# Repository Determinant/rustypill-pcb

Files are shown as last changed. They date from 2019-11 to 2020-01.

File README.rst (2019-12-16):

rustypill
---------

A uniform design for my daily/IoT DIY need.

Features
========

- STM32F103CBU6/STM32F411CEU6 microcontroller (required)
- All GPIOs are available
- Support optional HD44780 LCD (or "1602", with backlight) via I2C
- Support optional ESP8266 (WiFi module), via UART serial ports
- Support optional DS3231 (accurate RTC, with battery) via I2C
- Support optional AT24Cx (EEPROM) via I2C
- Support optional microSD via SPI
- Support optional custom I2C external board (such as OLED display)
- Convenient 10-pin IDC socket (A0-A7 which supports analog input, plus GND and V5 power)
- microUSB

PCB
===

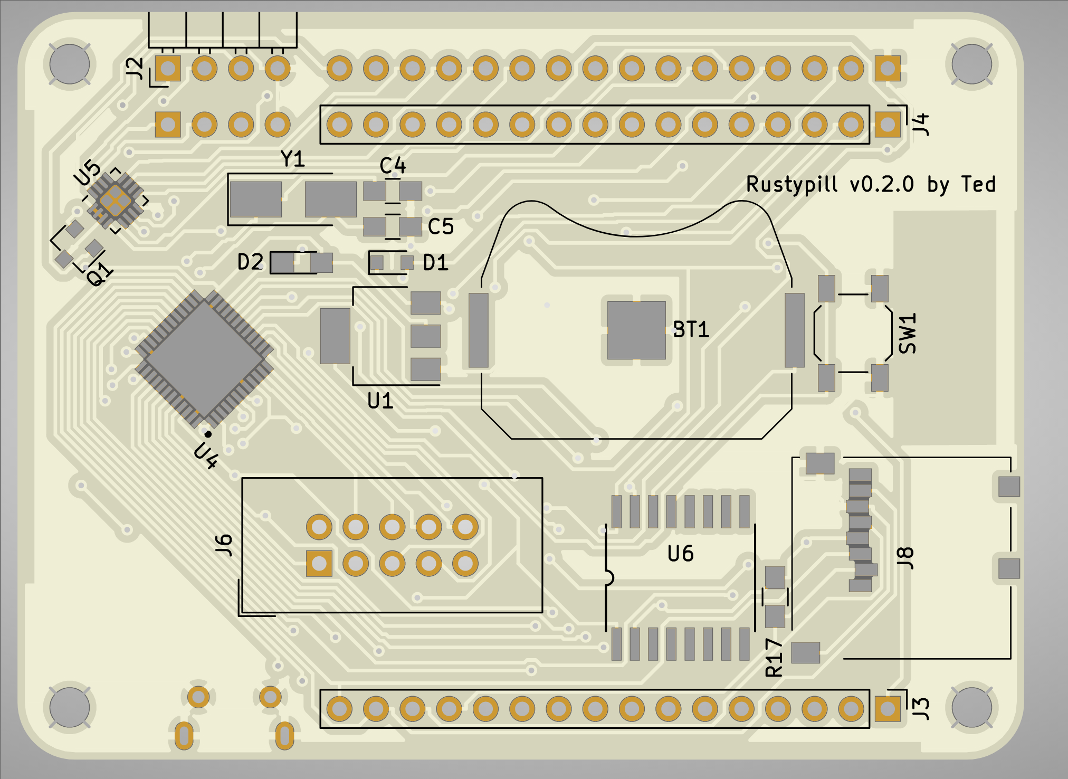
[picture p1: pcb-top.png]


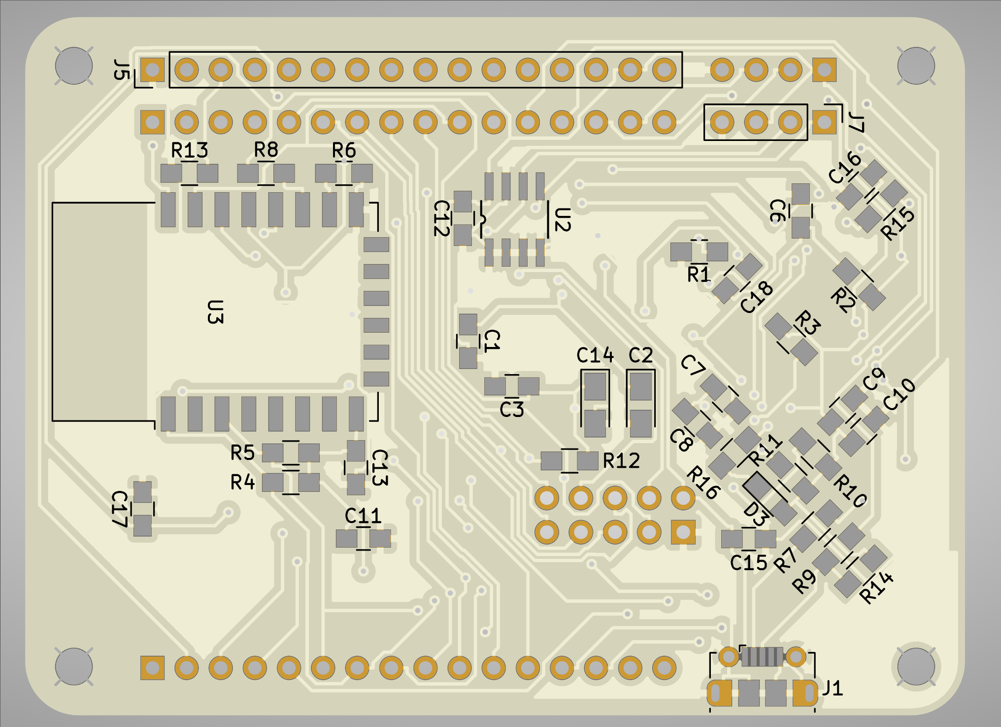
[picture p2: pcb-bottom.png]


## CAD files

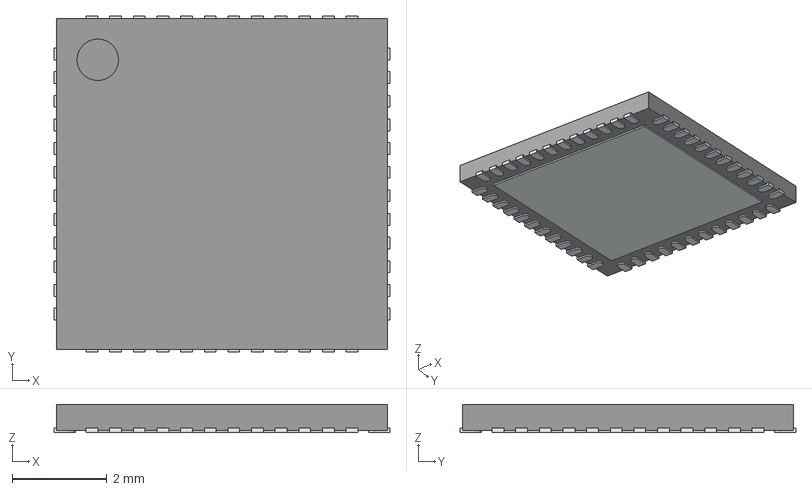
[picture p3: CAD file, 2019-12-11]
3D/STM32F411CEU6.stp
7.10 x 7.10 x 0.6 mm
ThermalPin
PinsArrayLR
PinsArrayTB

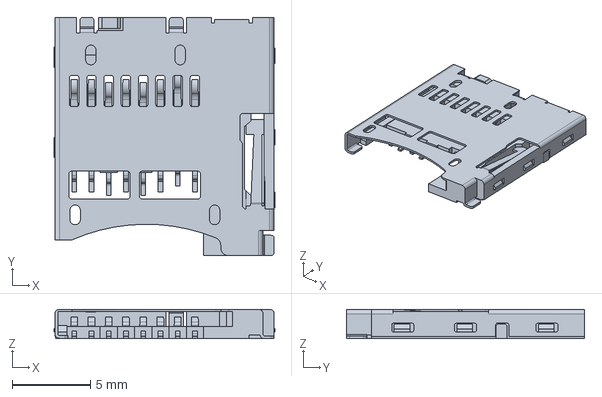
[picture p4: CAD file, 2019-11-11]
3D/47334-0001.stp
14.1 x 15.2 x 1.88 mm

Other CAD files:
3D/STM32F411CEU6.stl

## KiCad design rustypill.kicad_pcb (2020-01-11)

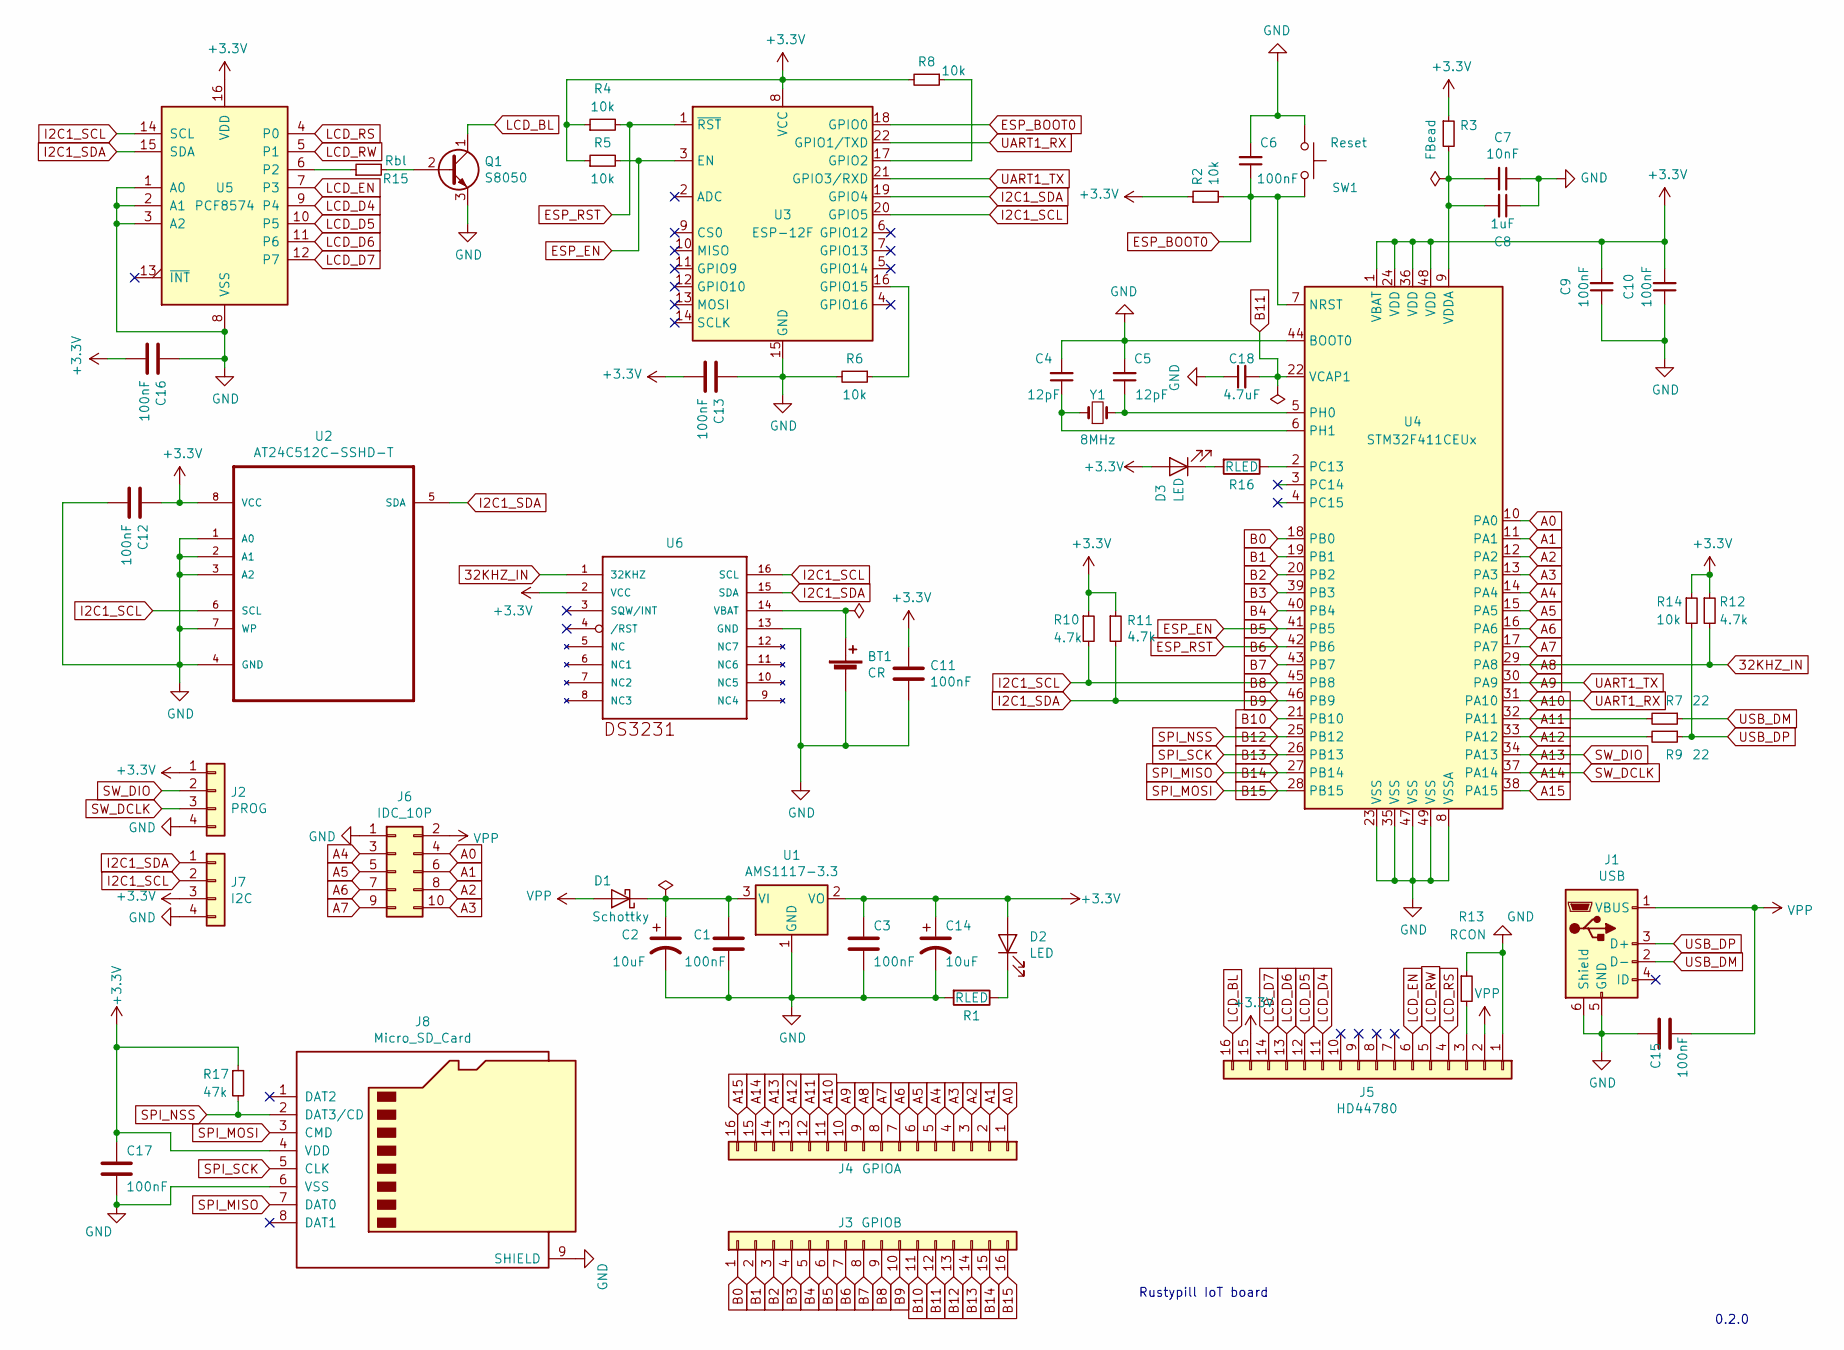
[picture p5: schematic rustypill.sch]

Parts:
BT1: CR; my3034_holder
C1, C3, C6, C9, C10, C11, C12, C13, C15, C16, C17: 100nF; C_0805_HandSoldering
C2, C14: 10uF; CP_Tantalum_Case-A_EIA-3216-18_Reflow
C4, C5: 12pF; C_0805_HandSoldering
C7: 10nF; C_0805_HandSoldering
C8: 1uF; C_0805_HandSoldering
C18: 4.7uF; C_0805_HandSoldering
D1: Schottky; D_0805
D2, D3: LED; LED_0805_HandSoldering
J1: USB; USB_Micro-B_Molex-105017-0001
J2: PROG; Pin_Header_Angled_1x04_Pitch2.54mm
J3: GPIOB; Pin_Header_Straight_1x16_Pitch2.54mm
J4: GPIOA; Pin_Header_Straight_1x16_Pitch2.54mm
J5: HD44780; Pin_Header_Straight_1x16_Pitch2.54mm
J6: IDC_10P; IDC-Header_2x05_P2.54mm_Vertical
J7: I2C; Pin_Header_Straight_1x04_Pitch2.54mm
J8: Micro_SD_Card; 473340001
Q1: S8050; SOT-23
R1, R16: RLED; R_0805_HandSoldering
R2, R4, R5, R6, R8, R14: 10k; R_0805_HandSoldering
R3: FBead; R_0805_HandSoldering
R7, R9: 22; R_0805_HandSoldering
R10, R11, R12: 4.7k; R_0805_HandSoldering
R13: RCON; R_0805_HandSoldering
R15: Rbl; R_0805_HandSoldering
R17: 47k; R_0805_HandSoldering
SW1: Reset; SW_SPST_SKQG
U1: AMS1117-3.3; SOT-223-3_TabPin2
U2: AT24C512C-SSHD-T; at24c512c-sshd-t
U3: ESP-12F; ESP-12E
U4: STM32F411CEUx; stm32f411ceu6
U5: PCF8574; VQFN-16-1EP_3x3mm_P0.5mm_EP1.68x1.68mm
U6: DS3231; ds3231
Y1: 8MHz; Crystal_SMD_5032-2pin_5.0x3.2mm_HandSoldering

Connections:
32KHZ_IN: J4.9, R12.2, U4.29 (PA8), U6.1 (32KHZ)
+3V3: C3.1, C9.2, C10.2, C11.1, C12.1, C13.2, C14.1, C16.2, C17.1, D2.2 (A), D3.2 (A), J2.1, J5.15, J7.3, J8.4 (VDD), R2.1, R3.1, R4.1, R5.1, R8.2, R10.1, R11.1, R12.1, R14.1, R17.1, U1.2 (VO), U2.8 (VCC), U3.8 (VCC), U4.1 (VBAT), U4.24 (VDD), U4.36 (VDD), U4.48 (VDD), U5.16 (VDD), U6.2 (VCC)
A0: J4.1, J6.4, U4.10 (PA0)
A1: J4.2, J6.6, U4.11 (PA1)
A2: J4.3, J6.8, U4.12 (PA2)
A3: J4.4, J6.10, U4.13 (PA3)
A4: J4.5, J6.3, U4.14 (PA4)
A5: J4.6, J6.5, U4.15 (PA5)
A6: J4.7, J6.7, U4.16 (PA6)
A7: J4.8, J6.9, U4.17 (PA7)
A9: J4.10, U3.21 (GPIO3/RXD), U4.30 (PA9)
A10: J4.11, U3.22 (GPIO1/TXD), U4.31 (PA10)
A11: J4.12, R7.2, U4.32 (PA11)
A12: J4.13, R9.2, U4.33 (PA12)
A13: J2.2, J4.14, U4.34 (PA13)
A14: J2.3, J4.15, U4.37 (PA14)
A15: J4.16, U4.38 (PA15)
B0: J3.1, U4.18 (PB0)
B1: J3.2, U4.19 (PB1)
B2: J3.3, U4.20 (PB2)
B3: J3.4, U4.39 (PB3)
B4: J3.5, U4.40 (PB4)
B5: J3.6, R5.2, U3.3 (EN), U4.41 (PB5)
B6: J3.7, R4.2, U3.1 (~RST), U4.42 (PB6)
B7: J3.8, U4.43 (PB7)
B8: J3.9, J7.2, R10.2, U2.6 (SCL), U3.20 (GPIO5), U4.45 (PB8), U5.14 (SCL), U6.16 (SCL)
B9: J3.10, J7.1, R11.2, U2.5 (SDA), U3.19 (GPIO4), U4.46 (PB9), U5.15 (SDA), U6.15 (SDA)
B10: J3.11, U4.21 (PB10)
B11: C18.2, J3.12, U4.22 (VCAP1)
B12: J3.13, J8.2 (DAT3/CD), R17.2, U4.25 (PB12)
B13: J3.14, J8.5 (CLK), U4.26 (PB13)
B14: J3.15, J8.7 (DAT0), U4.27 (PB14)
B15: J3.16, J8.3 (CMD), U4.28 (PB15)
ESP_BOOT0: C6.1, R2.2, SW1.2, U3.18 (GPIO0), U4.7 (NRST)
GND: BT1.2 (-), C1.2, C2.2, C3.2, C4.2, C5.2, C6.2, C7.1, C8.1, C9.1, C10.1, C11.2, C12.2, C13.1, C14.2, C15.1, C16.1, C17.2, C18.1, J1.5 (GND), J1.6 (Shield), J2.4, J5.1, J6.1, J7.4, J8.6 (VSS), J8.9 (SHIELD), Q1.3 (E), R1.2, R6.2, R13.1, SW1.1, U1.1 (GND), U2.1 (A0), U2.2 (A1), U2.3 (A2), U2.4 (GND), U2.7 (WP), U3.15 (GND), U4.8 (VSSA), U4.23 (VSS), U4.35 (VSS), U4.44 (BOOT0), U4.47 (VSS), U4.49 (VSS), U5.1 (A0), U5.2 (A1), U5.3 (A2), U5.8 (VSS), U6.13 (GND)
LCD_BL: J5.16, Q1.1 (C)
LCD_D4: J5.11, U5.9 (P4)
LCD_D5: J5.12, U5.10 (P5)
LCD_D6: J5.13, U5.11 (P6)
LCD_D7: J5.14, U5.12 (P7)
LCD_EN: J5.6, U5.7 (P3)
LCD_RS: J5.4, U5.4 (P0)
LCD_RW: J5.5, U5.5 (P1)
unnamed: BT1.1 (+), U6.14 (VBAT)
unnamed: C1.1, C2.1, D1.1 (K), U1.3 (VI)
unnamed: C4.1, U4.6 (PH1), Y1.1
unnamed: C5.1, U4.5 (PH0), Y1.2
unnamed: C7.2, C8.2, R3.2, U4.9 (VDDA)
unnamed: D2.1 (K), R1.1
unnamed: D3.1 (K), R16.2
unnamed: J5.3, R13.2
unnamed: Q1.2 (B), R15.2
unnamed: R6.1, U3.16 (GPIO15)
unnamed: R8.1, U3.17 (GPIO2)
unnamed: R15.1, U5.6 (P2)
unnamed: R16.1, U4.2 (PC13)
USB_DM: J1.2 (D-), R7.1
USB_DP: J1.3 (D+), R9.1, R14.2
VPP: C15.2, D1.2 (A), J1.1 (VBUS), J5.2, J6.2

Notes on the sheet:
Rustypill IoT board
0.2.0

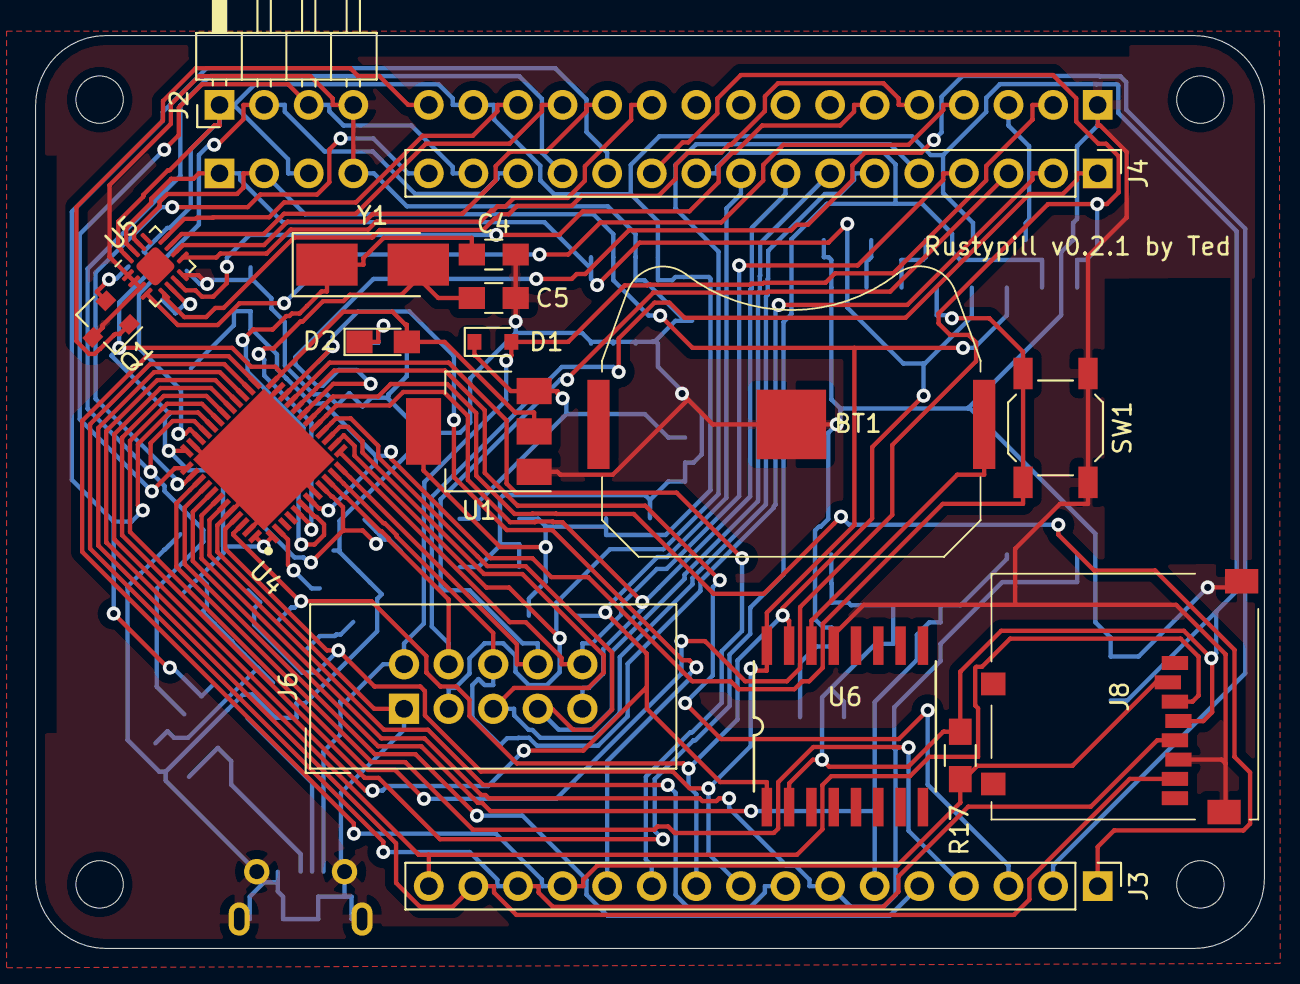
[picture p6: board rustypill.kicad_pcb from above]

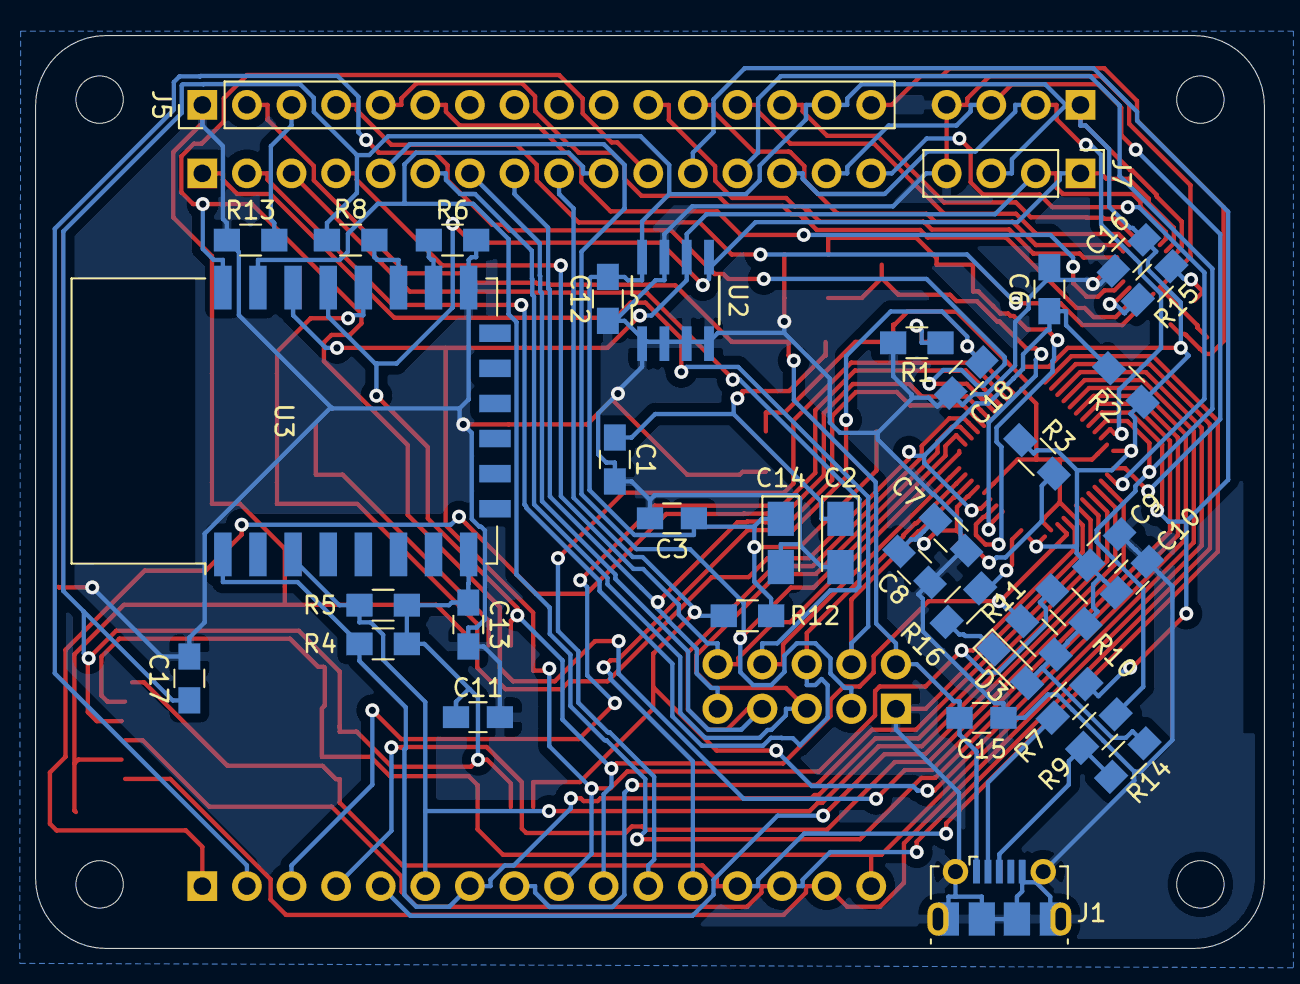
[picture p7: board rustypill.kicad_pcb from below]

Board: 2 copper layers, 70.0 x 52.0 mm, 60 parts (38 on the bottom side), 59 nets.

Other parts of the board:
 M1: MountingHole_2.7mm_M2.5
M2, M3, M4: MountingHole_2.7mm_M2.5

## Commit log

2019-11-07 finish pcb design
    [rustypill.kicad_pcb]
2019-11-07 finish v0.1.0
    [rustypill-B_Cu.gbr, rustypill-B_Mask.gbr, rustypill-B_Paste.gbr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]
2019-11-07 remove copper near the antenna
    [rustypill-B_Cu.gbr, rustypill-B_Mask.gbr, rustypill-B_Paste.gbr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]
2019-11-10 add more I2C features; better placement; etc
    [rustypill.kicad_pcb, rustypill.sch]
2019-11-10 reduce vias
    [rustypill.kicad_pcb]
2019-11-12 finish routing
    [rustypill.kicad_pcb, rustypill.sch]
2019-12-11 clean up
    [STM32F411CEU6.stl, STM32F411CEU6.stp, rustypill.kicad_pcb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]
2019-12-16 finish v0.2.0
    [rustypill-B_Cu.gbr, rustypill-B_Mask.gbr, rustypill-B_Paste.gbr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]
2020-01-11 fix the sdcard orientation issue
    [rustypill-B_Cu.gbr, rustypill-B_Mask.gbr, rustypill-B_Paste.gbr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]
